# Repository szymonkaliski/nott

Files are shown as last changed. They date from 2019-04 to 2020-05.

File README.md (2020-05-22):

# nótt

Standalone [mlr](https://monome.org/docs/norns/dust/tehn/mlr/) & [norns](https://monome.org/norns/) inspired sampler, looper and granular instrument.

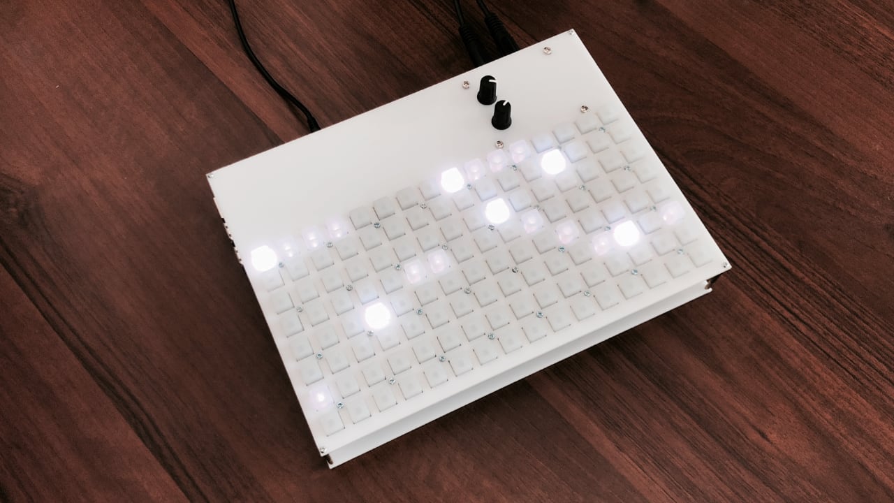
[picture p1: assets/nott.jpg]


**Warning**: instruction below is for a build from commit `da26d36081023a1721897fcc5c4f9a3c9ec9ea12` when NeoTrellis grid was soldered to Pisound. Since then I moved to having Pisound in the original case, and talking with monome through USB serial. If you want to follow this instruction, revert to the linked commit. If you want to use monome through USB serial, then ignore the soldering and GPIO parts.

## Usage

[Click here for detailed info.](./docs/USAGE.md)

## Hardware

- 1x Raspberry Pi 3B+
- 8x [Adafruit NeoTrellis](https://www.adafruit.com/product/3954)
- 8x [Elastomer for NeoTrellis](https://www.adafruit.com/product/1611)
- 1x [Blokas Pisound](https://blokas.io/pisound)

1. solder NeoTrellis into 2x4 grid
   - remember about [addressing](https://learn.adafruit.com/adafruit-neotrellis/tiling#addressing-2-11)
   - you can edit (and see my) address in [`./ui/ui.py`](./ui/ui.py) file
2. solder NeoTrellis to [Pisound GPIO](https://blokas.io/pisound/docs/Specs/#raspberry-pi-pins-used-by-pisound):

   | NeoTrellis | Pisound      |
   | ---------- | ------------ |
   | `GND`      | `GND`: `1`   |
   | `VIN`      | `3.3V`: `4`  |
   | `SDA`      | `BCM2`: `13` |
   | `SCL`      | `BCM3`: `14` |
   | `INT`      | `BCM5`: `5`  |

3. optionally, desolder MIDI ports and Raspberry Pi connection, and wire by hand for smaller form size

## Installation

1. setup Raspbian Lite on SD Card
2. ssh into Raspberry Pi
3. setup Pisound: `curl https://blokas.io/pisound/install-pisound.sh | sh`
4. enable `i2c` in `raspi-config`
5. install python deps:

```bash
sudo apt-get install -y python3-pip
sudo pip3 install --upgrade setuptools

sudo apt-get install -y python-smbus
sudo apt-get install -y i2c-tools
sudo apt-get install -y python3-liblo

pip3 install RPI.GPIO
pip3 install adafruit-blinka
pip3 install adafruit-circuitpython-neotrellis
```

6. install chuck from source (**notice the _patch_**):

```bash
mkdir ~/temp && cd ~/temp

git clone https://github.com/ccrma/chuck.git chuck-git

sudo apt-get install bison flex libasound2-dev libsndfile1-dev

cd chuck-git/src/
make linux-alsa

mkdir ~/.bin
cp chuck ~/.bin/chuck
```

7. `git clone git@github.com:szymonkaliski/nott.git ~/app && cd ~/app`
8. `./scripts/systemd-setup.sh`
9. `./scripts/systemd-start.sh`
10. optionally, disable `pisound-ctl`: `./scripts/systemd-disable-pisound-ctl.sh`

## Case

The STL & SVG files are available in [`./case/dist`](./case/dist) folder. I laser-cut mine in plexi.

If you want to work on the case:

1. `cd ./case`
2. `npm i`
3. open `model.js`
4. open `http://localhost:3000`

Case was designed in [modeler](https://github.com/szymonkaliski/modeler).

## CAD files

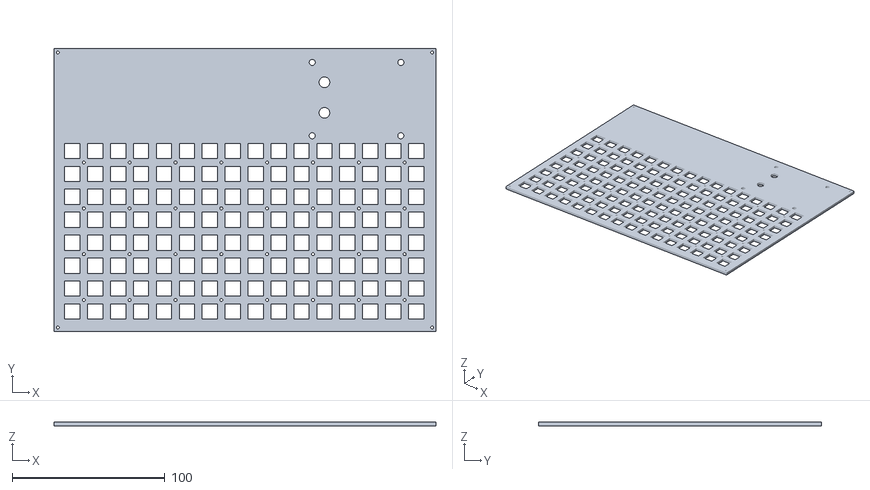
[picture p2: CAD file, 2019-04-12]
case/dist/case-top.stl
250.0 x 185.0 x 2.50

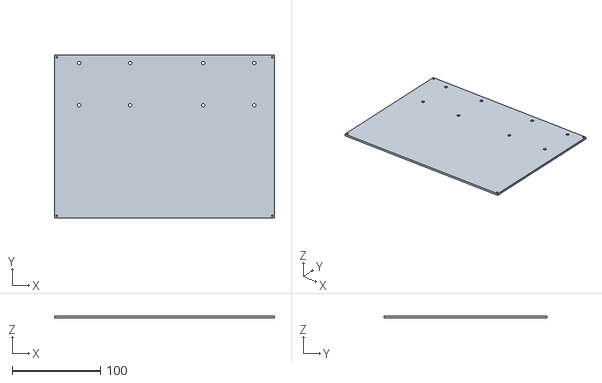
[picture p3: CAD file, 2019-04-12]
case/dist/case-bottom.stl
250.0 x 185.0 x 2.50

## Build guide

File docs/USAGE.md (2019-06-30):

# nótt usage instruction

There's four main cards controled by upper left buttons:
- `play` - main screen for looping/jumping
- `ctrl` - main control screen
- `vol` - volume and feedback control
- `opt` - random buttons, mainly granular-mode related

## play

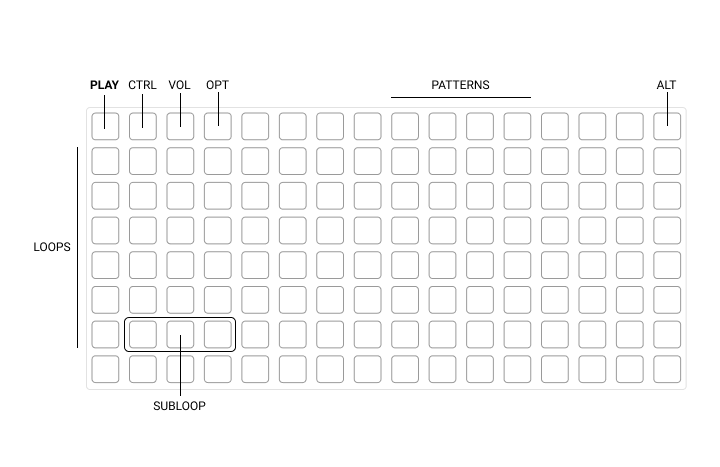
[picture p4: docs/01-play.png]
play


- `play` mode displays loop position
- touching any of the loop control points jumps to that position
- holding one of the jump positions, and then touching another one creates subloop

## ctrl

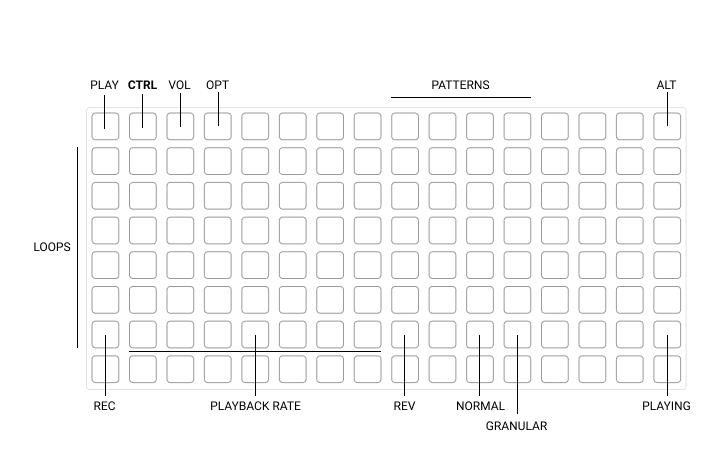
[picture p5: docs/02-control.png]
control


- `rec` turns recording on/off (multiple loops can record at the same time)
- playback rate controls speed of replay
- `rev` turns playing backwards on/off
- `normal` switches to normal (defaul) mode
- `granular` switches to granular playback mode
- playing toggles playback on/off
- to clear buffer, hold `alt` and touch `rec`

## vol

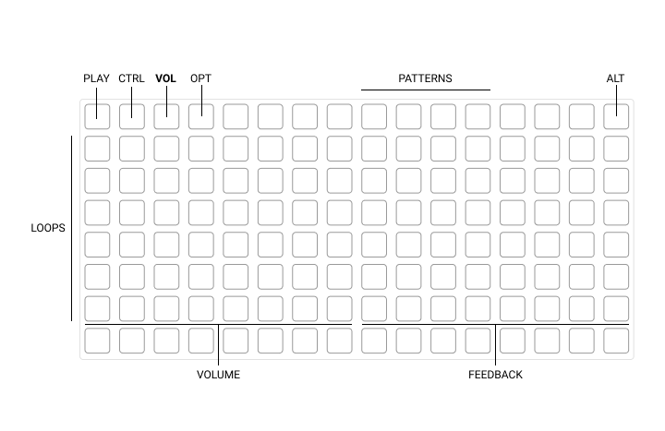
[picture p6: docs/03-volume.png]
volume


- `volume` controls loop volume
- `feedback` controls recording feedback (only influences the loop when `rec` is on)

## opt

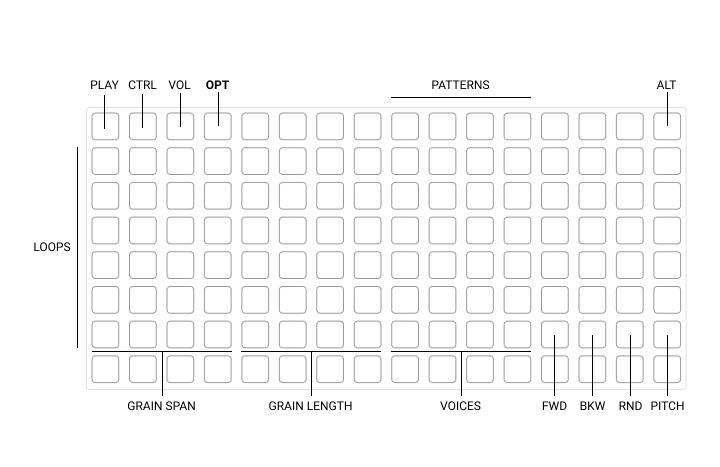
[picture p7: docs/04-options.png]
options


- these options only influence the loop in granular mode
- `span` controls the granules span around current playback position
- `length` controls length of the granules
- `voices` controls amount of granules
- `fwd` switches granules to play forward (default)
- `bkw` switches granules to play backward
- `rnd` switches granules to play in random direction
- `pitch` toggles on/off if sample playback speed influences granule playback speed (default to off)

## patterns

- touch one of the four pattern buttons to start recording
  - every action is recorded - not only playback position, but also volume, rate, etc.
- touch the pattern button to stop recording
- touch it again to start looping the recorded actions
- hold `alt` and touch the pattern to delete it

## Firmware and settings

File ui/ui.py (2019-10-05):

import liblo
import signal
import sys
import time

from consts import CHUCK_IN_PORT, CHUCK_OUT_PORT, CHUCK_HOST, LOOPS_COUNT
from row import Row
from topbar import Topbar
from patterns import Patterns

from monome import Monome


# setup chuck osc communication
chuck_in = liblo.ServerThread(CHUCK_IN_PORT, reg_methods=False)
chuck_out = liblo.Address(CHUCK_HOST, CHUCK_OUT_PORT)

# setup monome
monome = Monome()

# setup ui
rows = []


def chuck_send(path, loopId, *values):
    liblo.send(chuck_out, path, loopId, *values)


patterns = Patterns(chuck_send)


for i in range(LOOPS_COUNT):
    row = Row(i, i + 1, monome, patterns.on_msg)
    chuck_in.add_method("/status/" + str(row.id), "siiffffiff", row.on_osc_msg)
    chuck_in.add_method("/status_granular/" + str(row.id), "ffiii", row.on_osc_msg)
    rows.append(row)

topbar = Topbar(rows, patterns, monome)


# clean exit
def signal_handler(signal, frame):
    print("Nótt UI Cleanup")

    chuck_in.stop()
    patterns.stop()

    topbar.clear()

    for row in rows:
        row.clear()

    sys.exit(0)


signal.signal(signal.SIGINT, signal_handler)

# main loop

chuck_in.start()

print("Nótt UI Ready")

while True:
    monome.update()
    patterns.update()

    topbar.draw()

    for row in rows:
        row.draw()

    time.sleep(0.01)

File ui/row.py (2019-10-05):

from consts import COLOR, MODE, PLAYBACK_MODES, RATES
from monome import EDGE_RISING, EDGE_FALLING
from time import time

GRANULAR_SPANS = [1.0 / 128.0, 1.0 / 64.0, 1.0 / 32.0, 1.0 / 16.0]
GRANULAR_LENGTHS = [1.0 / 128.0, 1.0 / 64.0, 1.0 / 32.0, 1.0 / 16.0]
GRANULAR_VOICES = [2, 4, 8, 16]


class Row(object):
    # the world
    monome = None
    chuck_out = None

    # id & row
    id = None
    rowIdx = None

    # internal state
    mode = MODE.PLAY
    held_index = -1
    is_alt_held = False

    # from chuck
    playback_mode = None
    is_recording = False
    is_playing = False

    volume = 1.0
    feedback = 1.0

    playback_pos = 0.0
    subloop = (0.0, 1.0)

    rate = 1.0
    direction = 1

    granular_span = 0
    granular_length = 0
    granular_voices = 0
    granular_direction = 0
    granular_repitch = 0

    def __init__(self, id, rowIdx, monome, chuck_send_out):
        self.id = id
        self.rowIdx = rowIdx
        self.monome = monome

        self.chuck_send_out = chuck_send_out

        self.clear()

        for x in range(16):
            self.monome.set_callback(x, self.rowIdx, self.on_click)

    def clear(self):
        for x in range(16):
            self.set_led(x, COLOR.OFF)

    def set_led(self, x, color):
        self.monome.set_led(x, self.rowIdx, color)

    def to_chuck(self, path, *values):
        self.chuck_send_out(path, self.id, *values)

    def on_osc_msg(self, path, args):
        if "/status/" in path:
            self.playback_mode = args[0]
            self.is_playing = args[1]
            self.is_recording = args[2]
            self.playback_pos = args[3]
            self.volume = args[4]
            self.feedback = args[5]
            self.rate = args[6]
            self.direction = args[7]
            self.subloop = (args[8], args[9])

        if "/status_granular/" in path:
            self.granular_span = args[0]
            self.granular_length = args[1]
            self.granular_voices = args[2]
            self.granular_direction = args[3]  # 1 fwd, 2 bkwd, 3 rand
            self.granular_repitch = args[4]  # 1 on, 0 off

    def on_click(self, x, _, edge):
        if self.mode == MODE.PLAY:
            if edge == EDGE_RISING and 0 <= x < 16:
                is_sublooping = self.subloop[0] > 0.0 or self.subloop[1] < 1.0

                if self.held_index < 0:
                    self.held_index = x
                    self.to_chuck("/jump", x / 16)

                    if is_sublooping:
                        self.to_chuck("/subloop", 0.0, 1.0)
                else:
                    a, b = self.held_index / 16, x / 16
                    self.held_index = -1
                    self.to_chuck("/subloop", min(a, b), max(a, b))

            if edge == EDGE_FALLING and self.held_index == x:
                self.held_index = -1

        if self.mode == MODE.CONTROL_1 and edge == EDGE_RISING:
            if x == 0:
                if self.is_alt_held:
                    self.to_chuck("/clear", 1)
                else:
                    self.to_chuck("/recording", 0 if self.is_recording else 1)

            if 1 <= x <= 7:
                self.to_chuck("/rate", RATES[x - 1])

            if x == 8:
                self.to_chuck("/direction", 1 if self.direction < 0 else -1)

            if x == 10:
                self.to_chuck("/mode", PLAYBACK_MODES.STANDARD)

            if x == 11:
                self.to_chuck("/mode", PLAYBACK_MODES.GRANULAR)

            if x == 15:
                self.to_chuck("/play", 0 if self.is_playing else 1)

        if self.mode == MODE.CONTROL_2 and edge == EDGE_RISING:
            if 0 <= x <= 7:
                self.to_chuck("/volume", x / 7)

            if 8 <= x <= 16:
                self.to_chuck("/feedback", (x - 8) / 7)

        if self.mode == MODE.CONTROL_3 and edge == EDGE_RISING:
            if 0 <= x <= 3:
                self.to_chuck("/granular_span", GRANULAR_SPANS[x])

            if 4 <= x <= 7:
                self.to_chuck("/granular_length", GRANULAR_LENGTHS[x - 4])

            if 8 <= x <= 11:
                self.to_chuck("/granular_voices", GRANULAR_VOICES[x - 8])

            if x == 12:
                self.to_chuck("/granular_direction", 1)

            if x == 13:
                self.to_chuck("/granular_direction", 2)

            if x == 14:
                self.to_chuck("/granular_direction", 3)

            if x == 15:
                self.to_chuck(
                    "/granular_repitch", 0 if self.granular_repitch == 1 else 1
                )

    def draw(self):
        if self.mode == MODE.PLAY:
            playback_pos_idx = round(self.playback_pos * 16)
            is_sublooping = self.subloop[0] > 0.0 or self.subloop[1] < 1.0

            for i in range(0, 16):
                if i == playback_pos_idx:
                    self.set_led(
                        i, COLOR.WHITE if self.is_playing else COLOR.WHITE_MUTED
                    )
                elif i == round(self.subloop[0] * 16) and is_sublooping:
                    self.set_led(i, COLOR.WHITE_MUTED)
                elif i == round(self.subloop[1] * 16) and is_sublooping:
                    self.set_led(i, COLOR.WHITE_MUTED)
                else:
                    self.set_led(i, COLOR.OFF)

        if self.mode == MODE.CONTROL_1:
            self.set_led(0, COLOR.WHITE if self.is_recording else COLOR.WHITE_MUTED)

            for idx, rate in enumerate(RATES):
                if idx == 3:
                    self.set_led(
                        4, COLOR.WHITE if rate == self.rate else COLOR.WHITE_MUTED
                    )
                else:
                    self.set_led(
                        idx + 1, COLOR.WHITE if rate == self.rate else COLOR.OFF
                    )

            self.set_led(8, COLOR.WHITE if self.direction < 0 else COLOR.WHITE_MUTED)
            self.set_led(9, COLOR.OFF)

            self.set_led(
                10,
                COLOR.WHITE
                if self.playback_mode == PLAYBACK_MODES.STANDARD
                else COLOR.WHITE_MUTED,
            )

            self.set_led(
                11,
                COLOR.WHITE
                if self.playback_mode == PLAYBACK_MODES.GRANULAR
                else COLOR.WHITE_MUTED,
            )

            for i in range(12, 15):
                self.set_led(i, COLOR.OFF)

            self.set_led(15, COLOR.WHITE if self.is_playing else COLOR.WHITE_MUTED)

        if self.mode == MODE.CONTROL_2:
            for i in range(0, 8):
                self.set_led(
                    i, COLOR.WHITE_MUTED if i / 8 <= self.volume else COLOR.OFF
                )

            for i in range(8, 16):
                self.set_led(
                    i, COLOR.WHITE_MUTED if (i - 8) / 8 <= self.feedback else COLOR.OFF
                )
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

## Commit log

2019-03-23 clearing while replaying bugfix
    [patterns.py]
2019-04-07 first pass at case design with modeler
2019-04-09 model with exports
    [case-bottom.stl, case-top.stl]
2019-04-10 more screw holes
    [case-bottom.stl, case-top.stl]
2019-04-12 slice to svg with slic3r
    [case-bottom.stl, case-top.stl]
2019-04-13 proper case model
2019-06-30 clearing buffer and small fixes
    [row.py, topbar.py]
2019-10-06 adc 3->4
2020-09-06 Bump tree-kill from 1.2.1 to 1.2.2 in /case
    Bumps [tree-kill](https://github.com/pkrumins/node-tree-kill) from 1.2.1 to 1.2.2.
    - [Release notes](https://github.com/pkrumins/node-tree-kill/releases)
    - [Commits](https://github.com/pkrumins/node-tree-kill/compare/v1.2.1...v1.2.2)
